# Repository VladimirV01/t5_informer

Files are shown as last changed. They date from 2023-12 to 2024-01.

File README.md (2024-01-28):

# Lilygo T5 Pro Informer for Home Assistant
This repository contains all my relevant materials, configurations and information used at building a Lilygo T5 Pro Informer for Home Assistant, based on ESP32-S3 module.
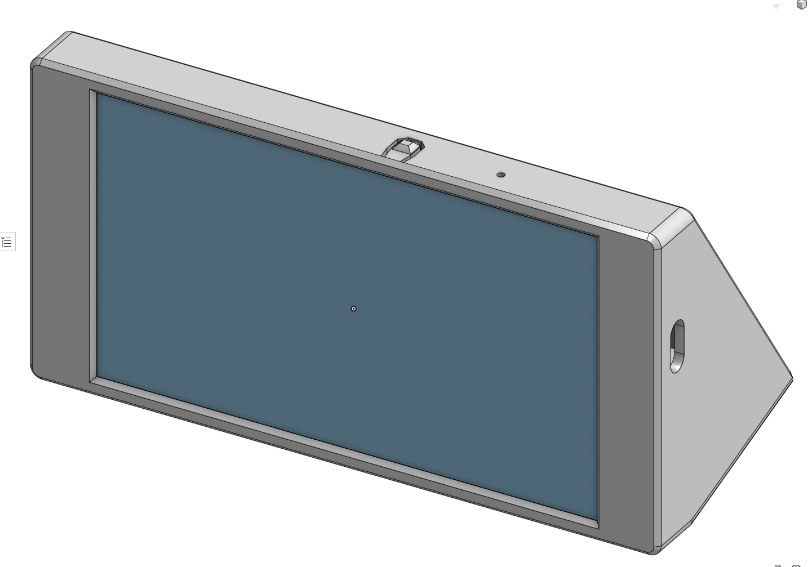
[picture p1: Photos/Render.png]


This project came to life mainly because I wanted to try the ePaper technology and check it out by myself. 
Initially I wanted to buy a bare display and make the electronics myself but I saw the Lilygo module and decided it is going to be faster to just buy it. 

At the moment of the build I had quite some trouble compiling it with ESPHome because the esp32-s3 was not fully supported at that time. As a result I had to to some digging on the internet to find a solution. 

## ESPHome Configuration File
The ESPHome yaml configuration file is `Configuration/t5_informer.yaml`. All the parameters are explained in the file.

You will notice that there are a bunch of repetitive sensors passed from HA to ESPHome for temperature forecast and event display. This is a workaround that I used to display the mentioned information since I could not manage to parse the JSON on the device itself... Any improvement here is welcome!

## ESPHome Compilation problems
As mentioned above, I had some problem compiling this project for esp32-s3 and after an extensive google search I found [this](https://github.com/esphome/feature-requests/issues/1960) feature request related to exactly Lilygo T5 Plus board.

I have folowed [this](https://github.com/esphome/feature-requests/issues/1960#issuecomment-1426388167) advice and added the file `Configuration/lilygo-t5-47-plus.json` to my device directory in `/config/esphome/.esphome/build/[my-device-name]/boards` and in the configuration file I specified the board as `lilygo-t5-47-plus` which worked like a charm and after all the manipulations I was able to flash the board and have it displaying my first letters on an ePaper display. :)

## Display Layout Configuration file
As you can observe in the ESPHome configuration file, the display layout code is in a different file and you can find it in `Configuration/t5_resources/my_display.yaml`.

In that file I have described all the bits and pieces that I consider important and hopefully it is explicit enough that anybody could easily change it to suit his/her needs.

The fonts and icons files are in the `Configuration/t5_resources/fonts/` don't forget to grab those and the `Configuration/t5_resources/common.h` file and add them to your desired directory in order to use when compiling the firmware. 

## Home Assistant part of configuration
To populate the weather and tasks related information I have added 2 template sensors on the home assistant side. 

I added them directly into the configuration.yaml file of the HA. Please check the file in `Configuration/HA_configuration.yaml`. It very clunky and I am aware there must be a more clever and better way to poll this info and if you know how to improve it, you are more than welcome. 

## 3D Print files for case
I have also designed a case for this specific board and the files to 3D print it are in the `3D_Files` directory. 

I printed it using PLA and designed the model to be printed without any support. 

[Here](https://cad.onshape.com/documents/7d4a7958a10177a50d182324/w/5a86303ea5b0b907208ba287/e/458f4cf96e62d17cedf1597b) if the link to the onshape project with the case. You can copy the project and add any changes and improvements you add because even though it is good enough for me, it is definitely far from being perfect and any improvement is welcome. 

**NOTE:** Please compile the firmware, flash it via USB and be sure the device is working and connecting to ESPHome before assembling the case. Due to some design flaws when the device is assembled the USB C connector can not reach the board. Sorry for that... :( Please modify the project and fix this issue if it annoys you too much. 

## Assembly steps
### Step 1: Get the parts
In the picture below you can see all the parts I used in the end to assemble the project. Plus add some screws and heated inserts that are not seen in the photo.
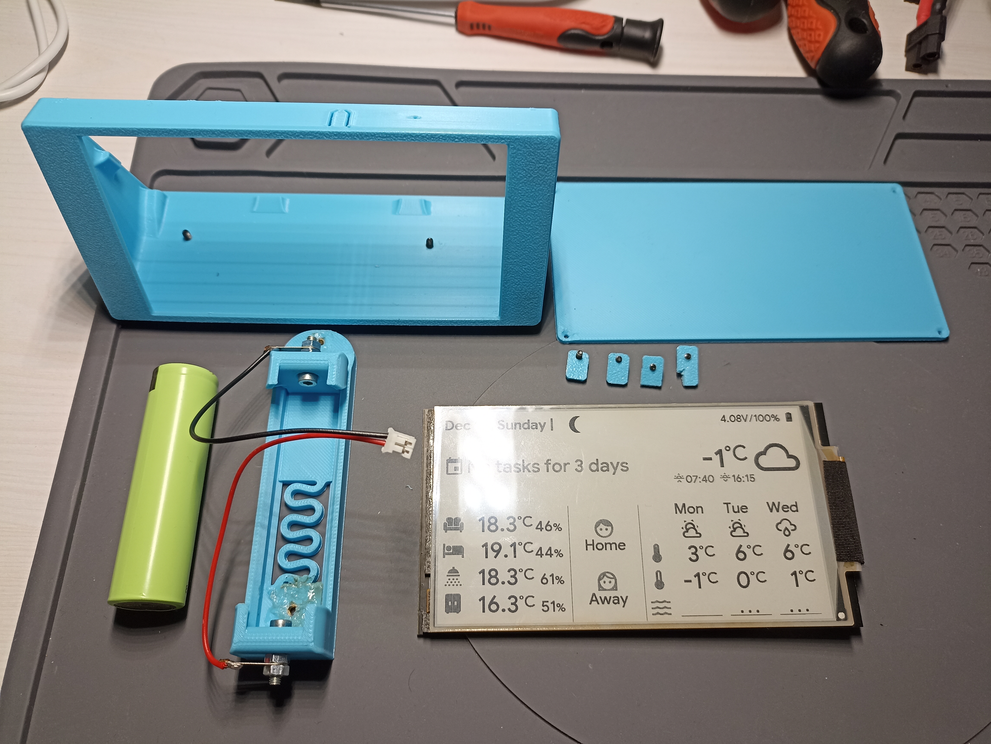
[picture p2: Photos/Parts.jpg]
Parts Parts for the project


### Step 2: Insert the bronze heated inserts into the case fixture points
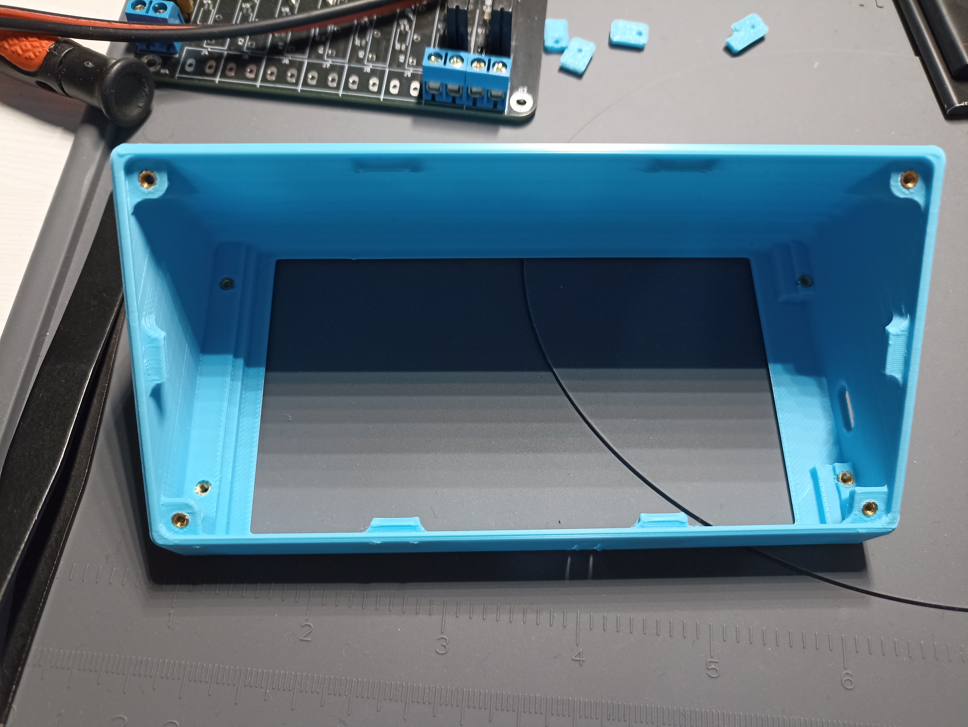
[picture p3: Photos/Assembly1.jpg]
Insert Heated Inserts Heated inserts


### Step 3: Insert the Lilygo Board
Insert the board
Please be careful at this step because you will have to fiddle the board around a bit to place it the right spot. I didn't think this step thoroughly enough and you will have to bend the upper side of the case outwards a bit so that the back lid support does not interfere with the board when inserting it.

Again: **Please be careful** not to damage your board or the ePaper display! (I have assembled an disassembled the device not less than 5 times and didn't damage mine so it is definitely doable but if you want to improve it, please adjust the 3D model using the shared link of the case project.)

### Step 4: Add the fixtures
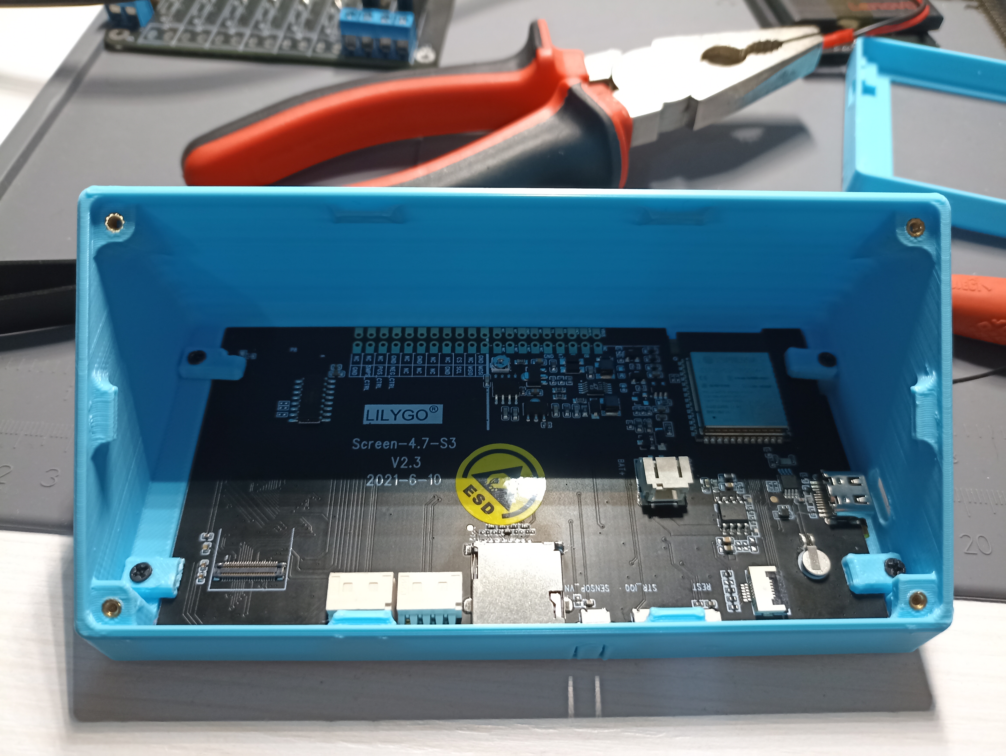
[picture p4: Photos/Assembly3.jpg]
Add the fixtures

Use some screws compatible with your heated inserts and add the printed fixtures to secure the board and the display in place.

You can see from the photos that I trimmed my fixtures after printed because those were interfering with some components on the board but on the current model this is fixed.

### Step 5: Check the functionality
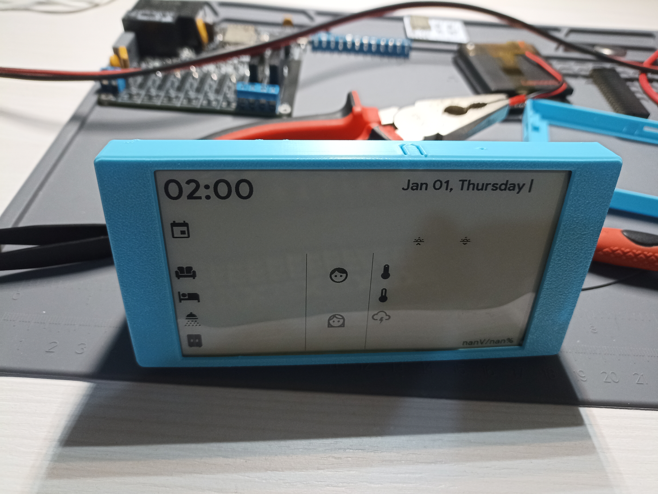
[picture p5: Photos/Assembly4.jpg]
Function check

At this point you can connect a battery and check if the device turns on and if everything is fine.

### Step 6: Add a battery
Initially I wanted to use an old phone battery that I had laying around as you can see from the photo below.
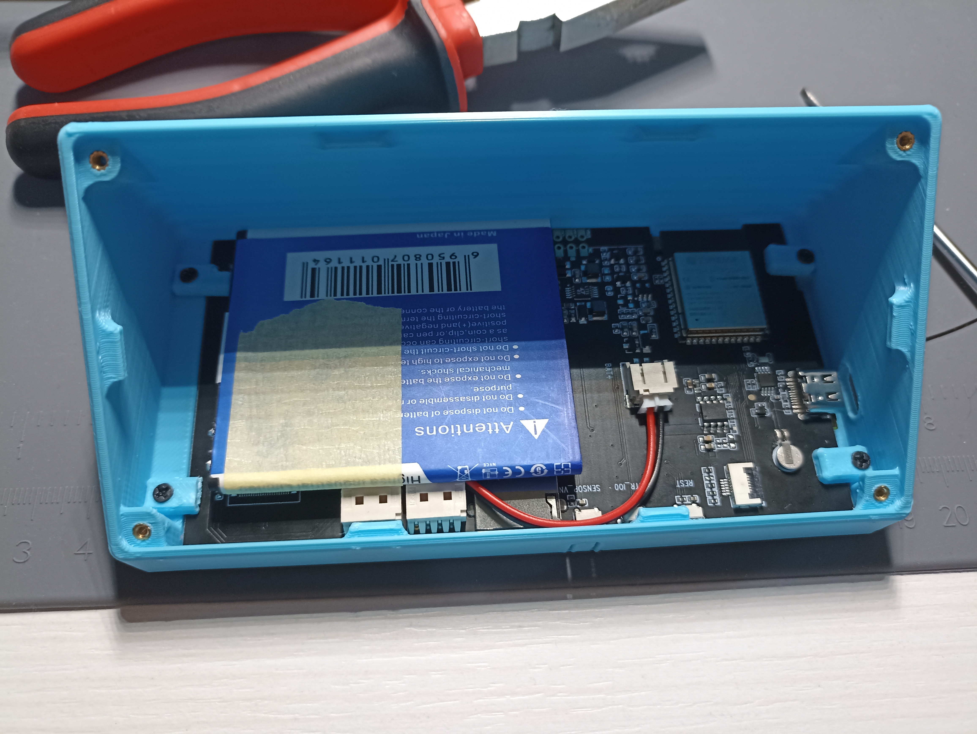
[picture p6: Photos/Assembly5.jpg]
Photo Battery Phone Battery


After some testing it turned out that the capacity degraded too much over time and the software is not yet very optimized for low enough power consumption. As a result the battery was drained very fast. So, I decided to use an 18650 cell that you can easily find anywhere. :) 

So I found [this](https://www.printables.com/model/75343-k014s-parametric-18650-battery-holder-opensource/comments/1284600) battery holder on Printables, printed it, inserted some bronze heated inserts in a very ugly way, drilled some holes in the bottom of the case and fixed it inside.

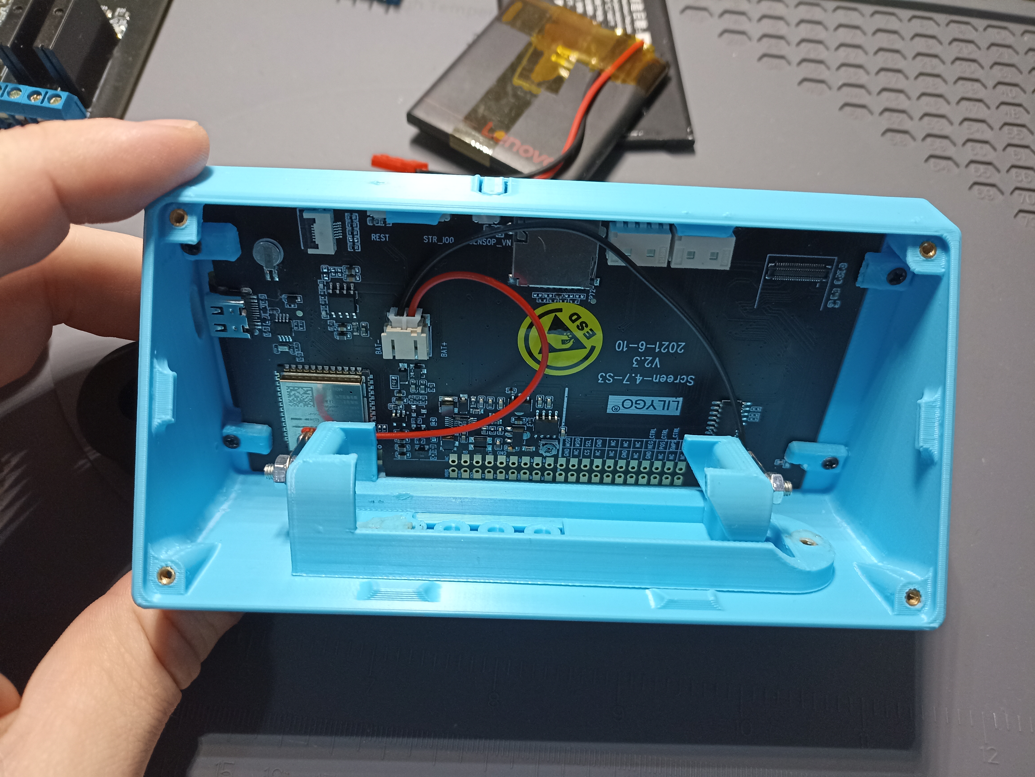
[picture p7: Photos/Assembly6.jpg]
Battery holder for 18650 inserted 18650 holder inserted


### Step 7: Charge the battery and insert it in the holder

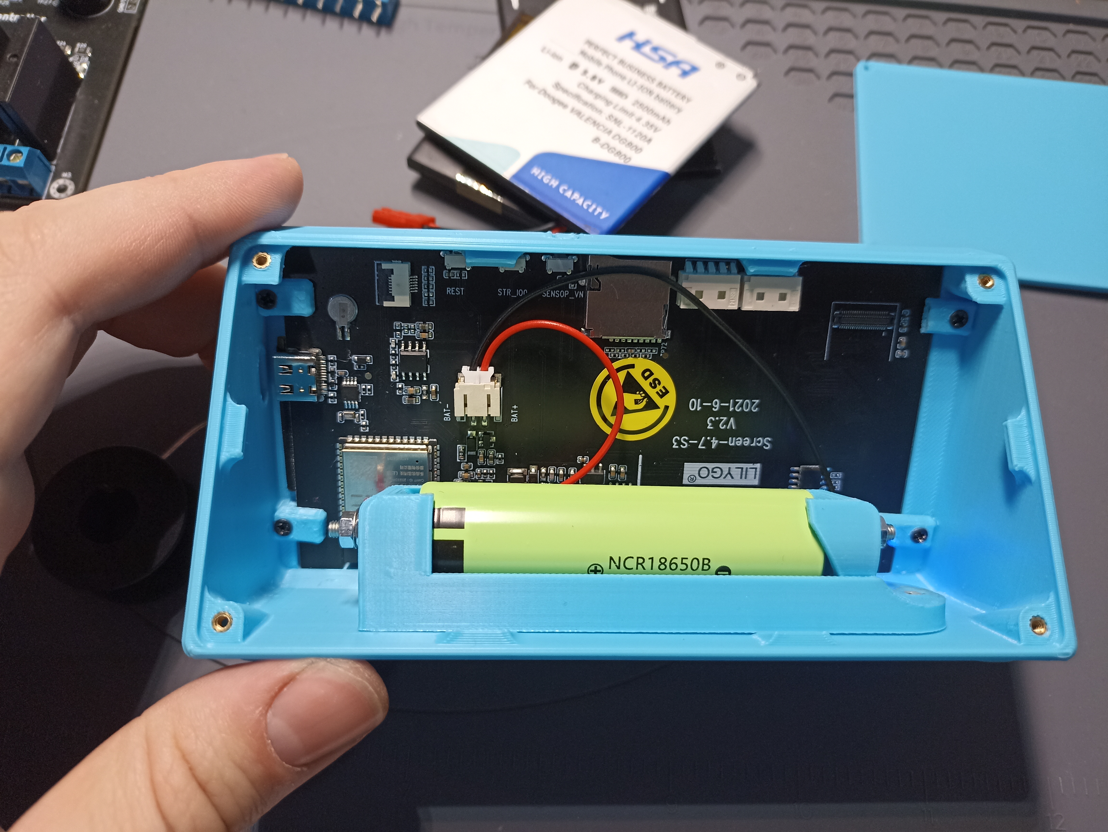
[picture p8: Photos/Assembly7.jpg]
Battery inserted Inserted battery


### Step 8: Screw the back lid in place

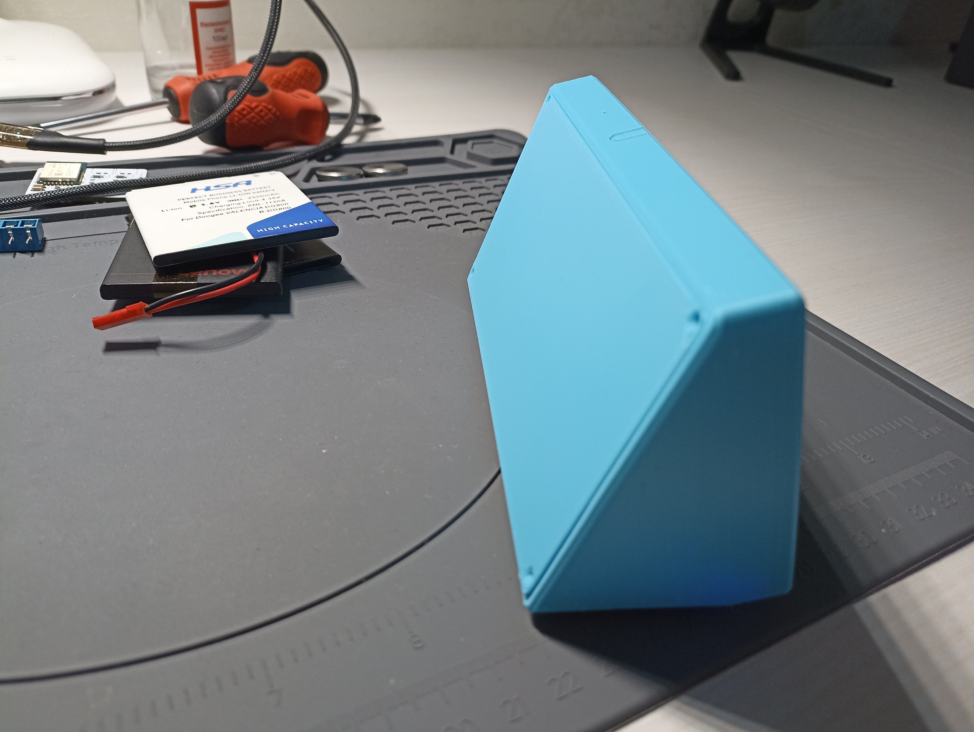
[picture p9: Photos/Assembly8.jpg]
Back lid inserted Inserted back lid


### Step 9: Enjoy!

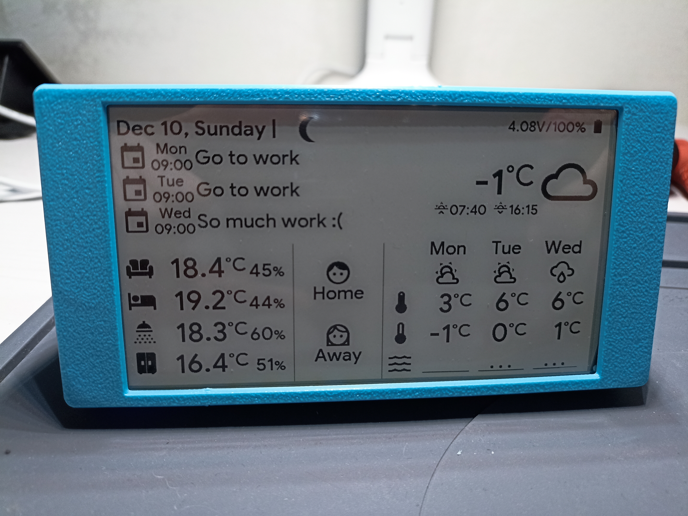
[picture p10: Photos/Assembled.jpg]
Assembled Informer


## References
Working on this project I designed the case entirely from scratch. However, the software was found in other repositories and was heavily modified by me to work for my needs.
Here are the references to the repositories and articles which I used.

[ESPHome configuration example](https://gist.github.com/Plawasan/4ae826b05aaa7812f3a191714ca47a50)

[Example of common.h file for translation functions used to convert text to icons](https://github.com/tolnai/esphome-dashboard-lilygo-t5/blob/main/common.h)

[Very useful and informative video from BeardedTinker](https://www.youtube.com/watch?v=yftae61X4i8)

[Nice display layout](https://www.reddit.com/r/homeassistant/comments/sdx5gg/yet_another_lilygo_t5_eink_esphome_dashboard/)

[Another example of ESPHome configuration](https://github.com/kotope/esphome_eink_dashboard/blob/main/eink-dashboard.yaml)

[Feature request issue which helped to compile the software](https://github.com/esphome/feature-requests/issues/1960)

## Some open issues:
1. When the battery discharges I have to take the back lid off and charge it because, as mentioned above, due to my design flaw I can not reach the connector with the USB C.
2. Make it update with a smaller frequency than hourly in the night.
3. Center the Tasks in the dedicated space when there are less than 3 tasks available.

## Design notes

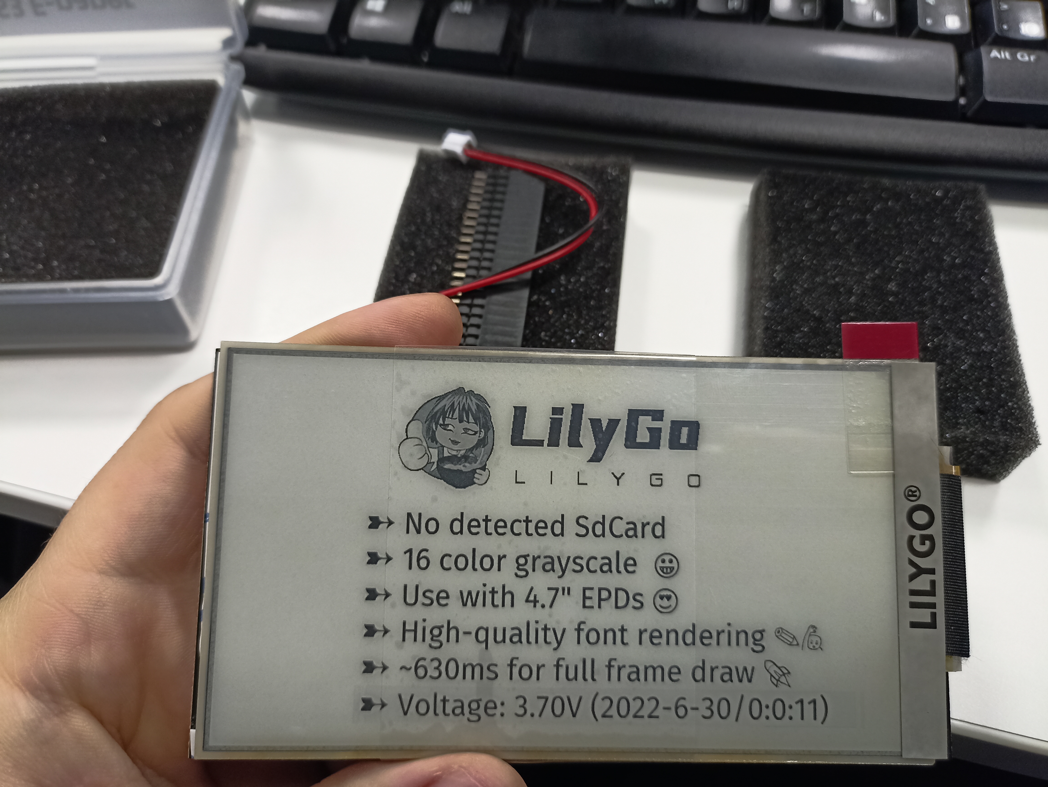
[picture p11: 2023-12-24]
Photos/EPaper.jpg

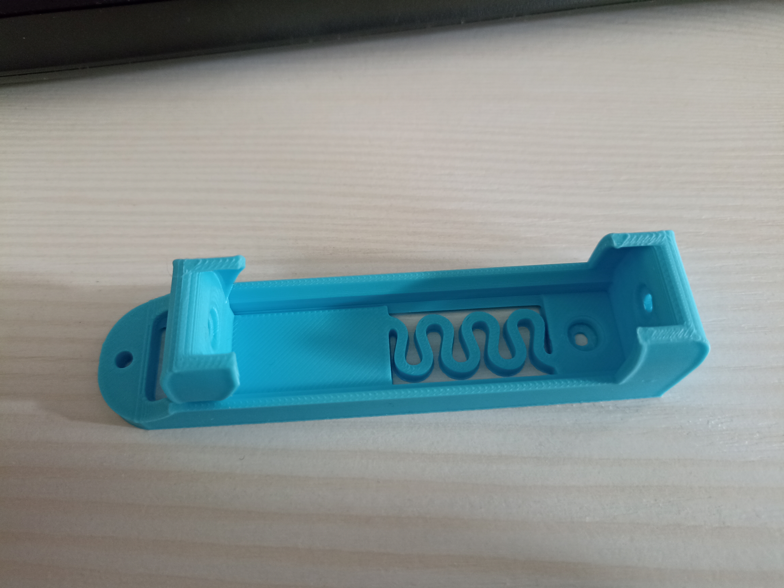
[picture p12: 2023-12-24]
Photos/Bat Holder.jpg

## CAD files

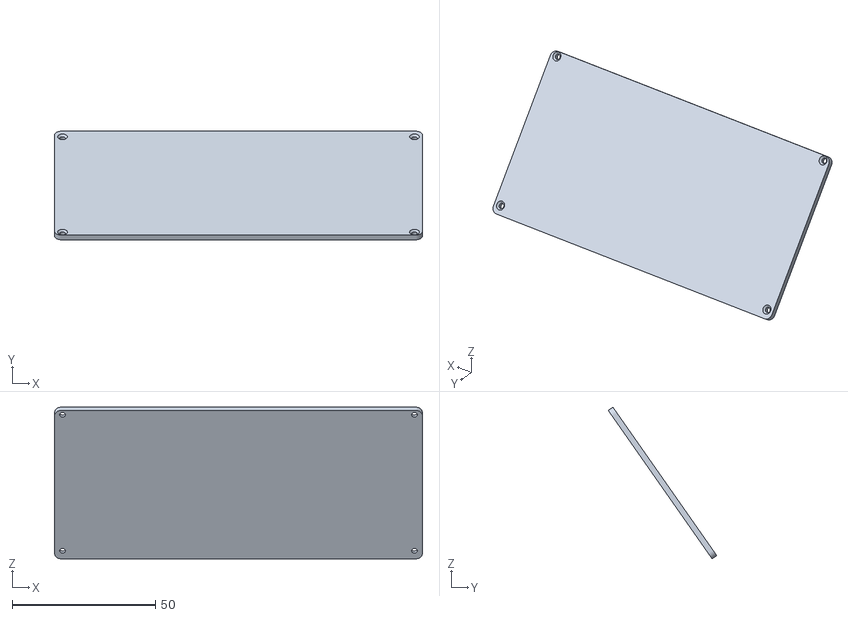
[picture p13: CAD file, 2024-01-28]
3D_Files/Lilygo Informer - Back Lid.stl
128.4 x 37.9 x 52.9

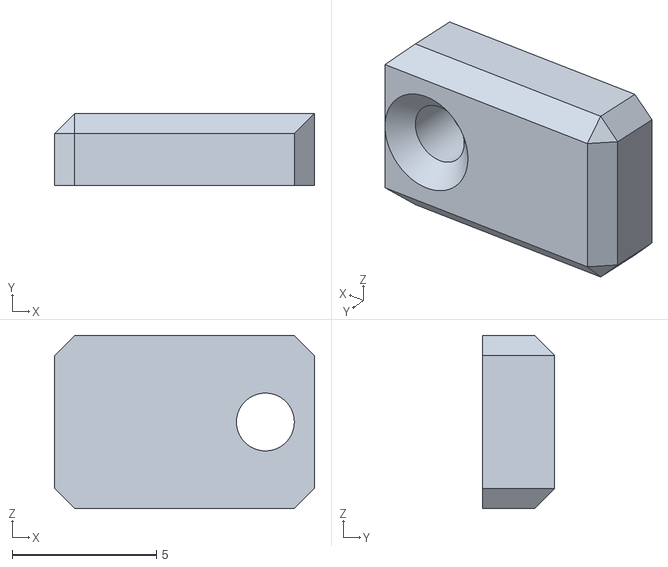
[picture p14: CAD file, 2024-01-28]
3D_Files/Lilygo Informer - Fixator Left.stl
9.00 x 2.50 x 6.00

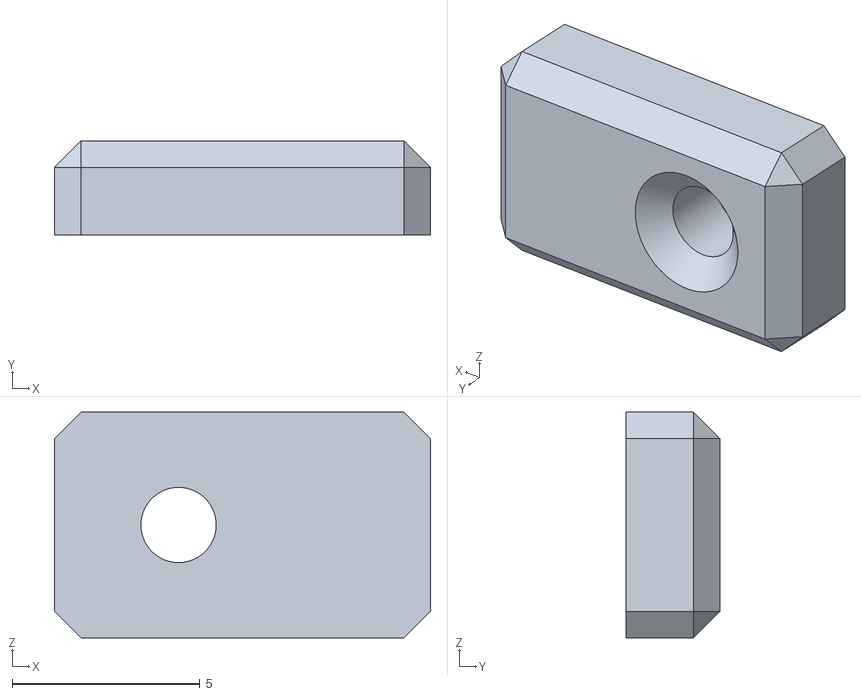
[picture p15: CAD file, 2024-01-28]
3D_Files/Lilygo Informer - Fixator Right.stl
10.0 x 2.50 x 6.00

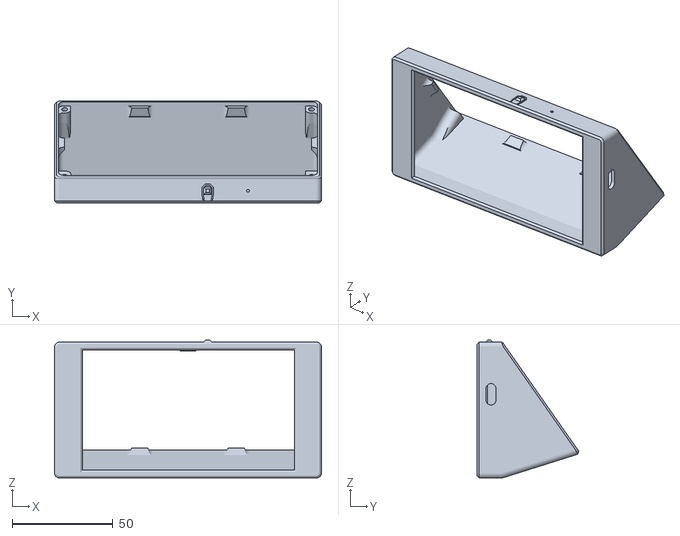
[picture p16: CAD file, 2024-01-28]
3D_Files/Lilygo Informer - Case.stl
132.8 x 50.6 x 68.6

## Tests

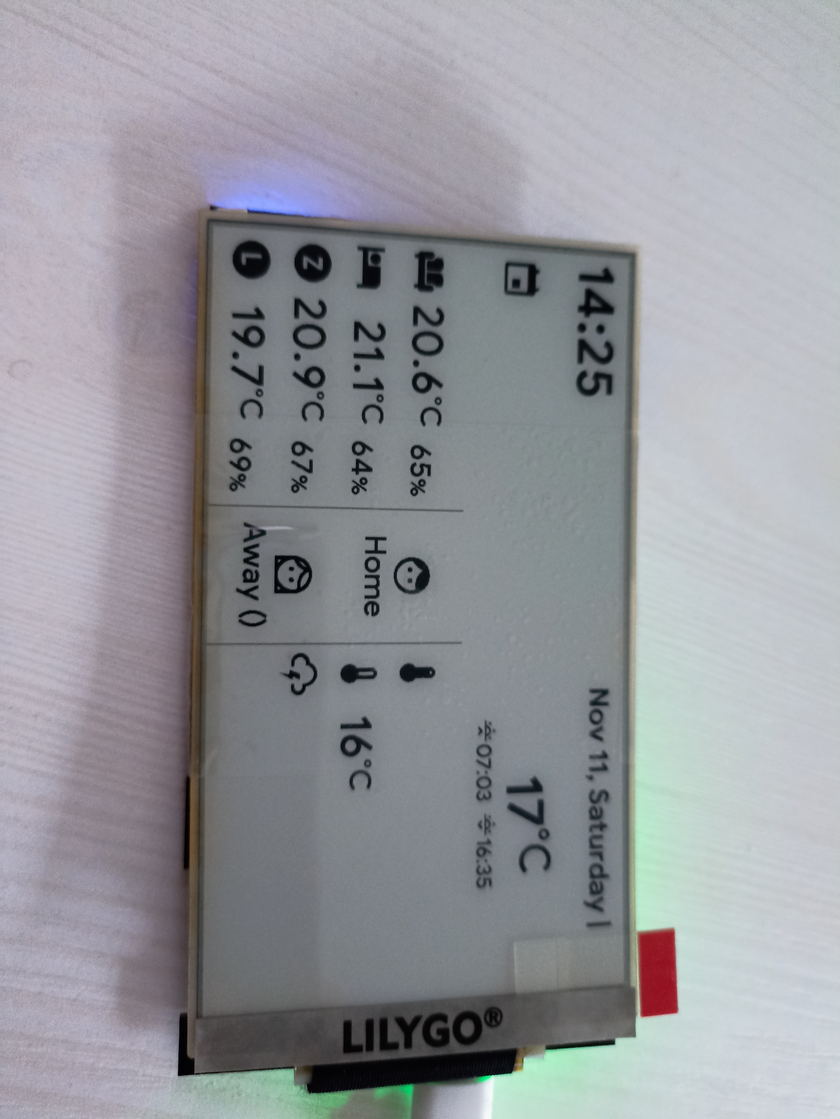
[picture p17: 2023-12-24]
Photos/First Results.jpg

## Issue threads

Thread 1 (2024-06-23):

Forecast is not working correct.

00107, 2024-06-23:
The weather forecast from Openweathermap is not working correctly. Day1 is correct, Day2 has incorrect values and Day3 provides no values. I've had this behavior for a few weeks, but I can't find a solution myself. Openweathermap itself provides correct prediction values and the API works.
Any ideas?
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

VladimirV01, 2024-06-23:
Hello @00107,

Please help me understand correctly the issue.
Was it ever working for you and suddenly stopped or you are only starting to configure it now?

Could you also share the homeasssitant configuration.yaml file part which covers the sensor that aggregates the forecast data?

00107, 2024-06-23:
Hello @VladimirV01
thanks for the quick response!
Yes, at the beginning it worked perfectly for several weeks. Suddenly the forecast values   for the third day were missing. Upon closer inspection I noticed that even for day 2 the values   did not match those shown by Openweathermap for this location. Day1 values are ok.
That's strange, isn't it?

This is my yaml of the sensor: https://wastebin.diefe.de/-3xY5a.yaml

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

VladimirV01, 2024-06-23:
@00107,

I have checked the sensor and it looks exactly as mine, which is still working as expected.

Could you please run the service "weather.get_forecasts" from home assistant and share the output?
I presume the issue is somewhere around here.

00107, 2024-06-23:
I first had to look at how to run a service... ;-) I hope I did it right. Here is the output:
`weather.openweathermap:
  forecast:
    - datetime: "2024-06-23T09:00:00+00:00"
      condition: partlycloudy
      temperature: 20.1
      pressure: 1019
      cloud_coverage: 19
      wind_speed: 4.43
      wind_bearing: 328
      uv_index: 5.14
      precipitation_probability: 0
      precipitation: 0
      apparent_temperature: 20
      dew_point: 14.7
      wind_gust_speed: 5.26
      humidity: 71
    - datetime: "2024-06-23T10:00:00+00:00"
      condition: partlycloudy
      temperature: 20.4
      pressure: 1019
      cloud_coverage: 21
      wind_speed: 3.74
      wind_bearing: 12
      uv_index: 4.52
      precipitation_probability: 0
      precipitation: 0
      apparent_temperature: 20.3
      dew_point: 14.8
      wind_gust_speed: 6.7
      humidity: 70
    - datetime: "2024-06-23T11:00:00+00:00"
      condition: partlycloudy
      temperature: 20.6
      pressure: 1019
      cloud_coverage: 22
      wind_speed: 4.5
      wind_bearing: 54
      uv_index: 2.96
      precipitation_probability: 0
      precipitation: 0
      apparent_temperature: 20.5
      dew_point: 14.7
      wind_gust_speed: 6.91
      humidity: 69
    - datetime: "2024-06-23T12:00:00+00:00"
      condition: partlycloudy
      temperature: 20.9
      pressure: 1019
      cloud_coverage: 25
      wind_speed: 6.05
      wind_bearing: 48
      uv_index: 4.66
      precipitation_probability: 0
      precipitation: 0
      apparent_temperature: 20.8
      dew_point: 14.8
      wind_gust_speed: 7.45
      humidity: 68
    - datetime: "2024-06-23T13:00:00+00:00"
      condition: cloudy
      temperature: 21.3
      pressure: 1018
      cloud_coverage: 64
      wind_speed: 6.48
      wind_bearing: 31
      uv_index: 6.12
      precipitation_probability: 0
      precipitation: 0
      apparent_temperature: 21.2
      dew_point: 14.7
      wind_gust_speed: 7.45
      humidity: 66
    - datetime: "2024-06-23T14:00:00+00:00"
      condition: cloudy
      temperature: 22.2
      pressure: 1017
      cloud_coverage: 67
      wind_speed: 7.45
      wind_bearing: 32
      uv_index: 3.17
      precipitation_probability: 0
      precipitation: 0
      apparent_temperature: 22.1
      dew_point: 15
      wind_gust_speed: 10.01
      humidity: 64
    - datetime: "2024-06-23T15:00:00+00:00"
      condition: cloudy
      temperature: 22.8
      pressure: 1017
      cloud_coverage: 76
      wind_speed: 9.07
      wind_bearing: 36
      uv_index: 2.61
      precipitation_probability: 0
      precipitation: 0
      apparent_temperature: 22.8
      dew_point: 15.5
      wind_gust_speed: 11.74
      humidity: 64
    - datetime: "2024-06-23T16:00:00+00:00"
      condition: rainy
      temperature: 22.4
      pressure: 1017
      cloud_coverage: 70
      wind_speed: 12.46
      wind_bearing: 31
      uv_index: 1.15
      precipitation_probability: 20
      precipitation: 0.16
      apparent_temperature: 22.5
      dew_point: 16.3
      wind_gust_speed: 13.82
      humidity: 69
    - datetime: "2024-06-23T17:00:00+00:00"
      condition: rainy
      temperature: 21.5
      pressure: 1017
      cloud_coverage: 73
      wind_speed: 11.12
      wind_bearing: 27
      uv_index: 0.64
      precipitation_probability: 23
      precipitation: 0.1
      apparent_temperature: 21.8
      dew_point: 17.1
      wind_gust_speed: 17.14
      humidity: 77
    - datetime: "2024-06-23T18:00:00+00:00"
      condition: cloudy
      temperature: 20.6
      pressure: 1017
      cloud_coverage: 78
      wind_speed: 7.02
      wind_bearing: 26
      uv_index: 0.26
      precipitation_probability: 3
      precipitation: 0
      apparent_temperature: 20.9
      dew_point: 17.5
      wind_gust_speed: 13.79
      humidity: 83
    - datetime: "2024-06-23T19:00:00+00:00"
      condition: rainy
      temperature: 18.9
      pressure: 1018
      cloud_coverage: 55
      wind_speed: 8.42
      wind_bearing: 31
      uv_index: 0
      precipitation_probability: 87
      precipitation: 0.24
      apparent_temperature: 19
      dew_point: 15.7
      wind_gust_speed: 7.13
      humidity: 83
    - datetime: "2024-06-23T20:00:00+00:00"
      condition: rainy
      temperature: 17.3
      pressure: 1019
      cloud_coverage: 52
      wind_speed: 9.61
      wind_bearing: 35
      uv_index: 0
      precipitation_probability: 82
      precipitation: 0.14
      apparent_temperature: 17.4
      dew_point: 15.1
      wind_gust_speed: 13.82
      humidity: 88
    - datetime: "2024-06-23T21:00:00+00:00"
      condition: cloudy
      temperature: 16.4
      pressure: 1019
      cloud_coverage: 57
      wind_speed: 8.93
      wind_bearing: 32
      uv_index: 0
      precipitation_probability: 54
      precipitation: 0
      apparent_temperature: 16.5
      dew_point: 14.8
      wind_gust_speed: 12.6
      humidity: 90
    - datetime: "2024-06-23T22:00:00+00:00"
      condition: partlycloudy
      temperature: 15.7
      pressure: 1019
      cloud_coverage: 48
      wind_speed: 8.5
      wind_bearing: 38
      uv_index: 0
      precipitation_probability: 32
      precipitation: 0
      apparent_temperature: 15.7
      dew_point: 14.3
      wind_gust_speed: 8.68
      humidity: 92
    - datetime: "2024-06-23T23:00:00+00:00"
      condition: partlycloudy
      temperature: 15.3
      pressure: 1019
      cloud_coverage: 42
      wind_speed: 8.35
      wind_bearing: 41
      uv_index: 0
      precipitation_probability: 15
      precipitation: 0
      apparent_temperature: 15.3
      dew_point: 14
      wind_gust_speed: 9.97
      humidity: 93
    - datetime: "2024-06-24T00:00:00+00:00"
      condition: partlycloudy
      temperature: 14.8
      pressure: 1019
      cloud_coverage: 37
      wind_speed: 8.96
      wind_bearing: 40
      uv_index: 0
      precipitation_probability: 3
      precipitation: 0
      apparent_temperature: 14.8
      dew_point: 13.8
      wind_gust_speed: 14.04
      humidity: 94
    - datetime: "2024-06-24T01:00:00+00:00"
      condition: sunny
      temperature: 14.5
      pressure: 1019
      cloud_coverage: 0
      wind_speed: 9
      wind_bearing: 40
      uv_index: 0
      precipitation_probability: 0
      precipitation: 0
      apparent_temperature: 14.4
      dew_point: 13.4
      wind_gust_speed: 17.1
      humidity: 94
    - datetime: "2024-06-24T02:00:00+00:00"
      condition: sunny
      temperature: 14.2
      pressure: 1019
      cloud_coverage: 2
      wind_speed: 8.75
      wind_bearing: 46
      uv_index: 0
      precipitation_probability: 0
      precipitation: 0
      apparent_temperature: 14.1
      dew_point: 13.1
      wind_gust_speed: 16.85
      humidity: 95
    - datetime: "2024-06-24T03:00:00+00:00"
      condition: sunny
      temperature: 13.8
      pressure: 1019
      cloud_coverage: 4
      wind_speed: 8.78
      wind_bearing: 45
      uv_index: 0
      precipitation_probability: 0
      precipitation: 0
      apparent_temperature: 13.8
      dew_point: 12.9
      wind_gust_speed: 16.45
      humidity: 95
    - datetime: "2024-06-24T04:00:00+00:00"
      condition: sunny
      temperature: 13.8
      pressure: 1019
      cloud_coverage: 4
      wind_speed: 9.07
      wind_bearing: 44
      uv_index: 0.1
      precipitation_probability: 0
      precipitation: 0
      apparent_temperature: 13.7
      dew_point: 12.9
      wind_gust_speed: 18.86
      humidity: 95
    - datetime: "2024-06-24T05:00:00+00:00"
      condition: sunny
      temperature: 15.1
      pressure: 1019
      cloud_coverage: 4
      wind_speed: 9
      wind_bearing: 47
      uv_index: 0.42
      precipitation_probability: 0
      precipitation: 0
      apparent_temperature: 15.1
      dew_point: 14
      wind_gust_speed: 25.81
      humidity: 94
    - datetime: "2024-06-24T06:00:00+00:00"
      condition: sunny
      temperature: 17
      pressure: 1019
      cloud_coverage: 3
      wind_speed: 13.21
      wind_bearing: 57
      uv_index: 1.15
      precipitation_probability: 0
      precipitation: 0
      apparent_temperature: 17.1
      dew_point: 15
      wind_gust_speed: 25.34
      humidity: 89
    - datetime: "2024-06-24T07:00:00+00:00"
      condition: sunny
      temperature: 18.7
      pressure: 1019
      cloud_coverage: 0
      wind_speed: 14.44
      wind_bearing: 64
      uv_index: 2.4
      precipitation_probability: 0
      precipitation: 0
      apparent_temperature: 18.8
      dew_point: 15.7
      wind_gust_speed: 22.64
      humidity: 83
    - datetime: "2024-06-24T08:00:00+00:00"
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
00107, 2024-06-23:
I have the feeling that it is due to the query type. If I select "hourly" when running the service, the values   end after two days. If I select "daily" I get forecast data for the next 7 days.

For testing purposes I set the configuration.yaml to Daily. Now I get values   for day 3, but the min/max calculation and condition is no longer correct. --> https://wastebin.diefe.de/YoqZ5c.yaml

 I use API V3.0, could it be related to that?

VladimirV01, 2024-06-23:
Yes, you are correct. Your hourly forecast contains data for current and two more days, however the informer show the data for the next 3 days.

On the other hand, you could use the daily forecast built into openwethermap sin e it is available for you, and there is no need to make all the calculations, as I did.

If you want to share a sample of daily forecast returned by the service, I can check later today how the sensor could be modified to use your data.

00107, 2024-06-23:
> If you want to share a sample of daily forecast returned by the service, I can check later today how the sensor could be modified to use your data.

That would be great, thank you! :)
Sample data of daily forecast: https://wastebin.diefe.de/3n0IPc.yaml

00107, 2024-06-23:
@VladimirV01
I have tried to adapt the code myself in the meantime. It works so far, but I am not sure if everything is correct. Unfortunately, my coding knowledge is not that good...
https://wastebin.diefe.de/0b+5mb.yaml

VladimirV01, 2024-06-23:
@00107,

Your template looks good!

Unfortunately I can not test it on my setup since the daily forecast is not available for the free version, but it should be working fine.
Does it display the correct information on your device?

00107, 2024-06-23:
Yes, the display looks good so far.
Thanks again for your great work and support. I think this issue can be closed.

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

00107, 2024-06-23:
Yes, the display looks good so far.
Thanks again for your great work and support. I think this issue can be closed.

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

Closed 2024-06-23.

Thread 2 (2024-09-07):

Error in the code

balbulator, 2024-09-07:
Hello, I want to thank you for the good work. Checking the operation of the weather forecast sensors in HA, I saw errors in the code, namely extra brackets in the forecast attributes
You do:
`day2_condition: "{{ (full_data['weather.openweathermap']['forecast'] | selectattr('datetime', 'search', (now().date() + timedelta(days=2)) | string ) | join(', ', attribute='condition') }}"`
and it should be like this:
`"{{ full_data['weather.openweathermap']['forecast'] | selectattr('datetime', 'search', (now().date() + timedelta(days=2)) | string ) | join(', ', attribute='condition') }}"`
this is seen in multiple attributes (the first parenthesis is redundant)
Sorry for my English

VladimirV01, 2024-09-07:
Hello @balbulator,

Thank you for pointing it out to me.
I do agree there are errors and the general configuration example was awful. :)

Anyway, I took this opportunity and used some AI magic to rewrite the HA configuration example and make it more readable, optimized and efficient.
Please take a look and if you find something else which is wrong, don't hesitate to point it out to me in a new issue!

VladimirV01, 2024-09-07:
Actually, I was too naïve to believe that the AI "improved" code was actually going to work, so after testing it turned out to be broken.
As a result I reverted to the initial config, just removed the suggested parentheses.

Closed 2024-09-07.

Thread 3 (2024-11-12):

Screw size?

chinswain, 2024-11-12:
I've just printed your case and need to order some of the heated insert and screws, could I ask what sizes you used?

VladimirV01, 2024-11-13:
Hello @chinswain,
I have used M2x5 screws and the inserts are M2x5x5.

chinswain, 2024-11-13:
Thanks - ordered and printing the case now!

Closed 2024-11-13.

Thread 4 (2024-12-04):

Operating time on battery ?

minigranis, 2024-12-04:
Hello.
Intresting projekt, can you tell me how long the battery lasts in your application ?

Brg

VladimirV01, 2024-12-04:
Hello.

This is complex question. In my application with the code posted on the repository it was working around 5-6 days for me when the battery was healthy. And this was way below my expectations. It demotivated me to work on improving the project.

Since then, I have discharged the battery under the lower allowed threshold and its capacity has degraded. Now it works around 3 days on a charge.

Over discharging the battery is really a concern in this application because the board has no protection integrated for this scenario. You should either send some alarms to your phone from HASS when the battery is low, and charge it before its voltage is below allowed values or add a cheap battery protection PCB, which will protect the battery.

Also, there are several improvements which can be made to the code and this should have significant impact on battery life.
1. Improve the code to update only once after wake up, when all the needed data is collected and ready to be presented. _Currently it updates 3 or 4 times when it wakes up._
2. Make the sleep time adaptive and don't wake up ad night.
3. Keep track if there is somebody at home or not. If nobody is at home, immediately go back to sleep without updating the screen.

When I have some spare time and motivation, maybe I will work on implementing the mentioned improvements.

Cheers!

minigranis, 2024-12-05:
Thanks, I know its a complex matter but your answer has given me an idea as what to expect.

Closed 2024-12-05.

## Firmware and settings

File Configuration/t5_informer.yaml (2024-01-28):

---
substitutions:
  device: t5_informer
  name: "Lilygo Informer"
  ip_address: 192.168.100.75
  ip_gw: 192.168.100.1
  ip_netmask: 255.255.255.0
  run_time: 2min
  sleep_time: 1h
  night_sleep_time: 6h # This is not used yet

esphome:
  name: ${device}
  friendly_name: ${name}
  includes:
    - t5_resources/common.h
  on_boot:
    then:
      - pcf8563.read_time:  # Update the RTC
      - script.execute: sleep_routine  # Running the script to prevent the device from entering deep sleep if there is an update pending.

  platformio_options:
    board_dir: boards
    board: lilygo-t5-47-plus

esp32:
  variant: esp32s3
  board: lilygo-t5-47-plus
  framework:
    type: arduino

logger:

api:
  encryption:
    key: <EDITED>

ota:

wifi:
  networks:
    - ssid: !secret iot_network_ssid
      password: !secret iot_network_password
  manual_ip:
    static_ip: ${ip_address}
    gateway: ${ip_gw}
    subnet: ${ip_netmask}

  ap:
    ssid: "AP ${name}"
    password: !secret wifi_ap_password

captive_portal:

web_server:
  port: 80
  include_internal: True

sun:
  latitude: 47.032292°
  longitude: 28.766057°

binary_sensor:
  - platform: homeassistant # This imports the input boolean from the homeassistant to check if there is pending update
    id: update
    internal: true
    entity_id: input_boolean.esphome_pending_update
# The physical button is commented because it is used for wake up from deep sleep. 
# If you want to use it for other purposes, comment the deep sleep section   
#  - platform: gpio
#    pin: 
#      number: GPIO21 #was GPIO39 on the previous board
#      inverted: true
#    name: "Button 1"
#    on_press:
#      - logger.log: Physical Button Pressed



i2c:
  sda: GPIO18
  scl: GPIO17
  scan: false
  id: rtc_bus
  frequency: 100khz

time:
  - platform: pcf8563
    id: pcf_time
    address: 0x51  
    update_interval: never
  - platform: homeassistant
    id: ntp
    timezone: Europe/Chisinau
    on_time_sync:
      then:
        - pcf8563.write_time:
        - component.update: sunrise
        - component.update: sunset

external_components:
  - source: github://nickolay/esphome-lilygo-t547plus
    components: ["t547"]
  - source: github://kaeltis/esphome-lilygo-t547plus
    components: ["lilygo_t5_47_battery"]

sensor:
  - platform: lilygo_t5_47_battery
    id: battery_voltage
    voltage:
      name: "Battery Voltage"

  - platform: template
    name: "Battery Percentage"
    id: battery_percentage
    lambda: |-
      // tweak values in mapping for calibration
      // 4.1 = max voltage
      // 3.3 = min voltage
      float y = (id(battery_voltage).voltage->state - 3.3) * 100.0 / (4.1 - 3.3);
      if (y < 100.0) 
      { return y; } 
      else if (y < 0)
      { return 0.0; }
      else { return 100.0; };
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

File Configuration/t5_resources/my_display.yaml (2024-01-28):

---
font:
  - file: "t5_resources/Google_Sans_Medium.ttf"
    id: font_small
    size: 28    
    glyphs: |-
      !"%()+=,-_.:°0123456789ABCDEFGHIJKLMNOPQRSTUVWXYZ abcdefghijklmnopqrstuvwxyz'/&|ÁÉÍÓÖŐÚÜŰáéíóöőúüű
  - file: "t5_resources/Google_Sans_Medium.ttf"
    id: font_medium
    size: 38
    glyphs: |-
      !"%()+=,-_.:°0123456789ABCDEFGHIJKLMNOPQRSTUVWXYZ abcdefghijklmnopqrstuvwxyz'/&|ÁÉÍÓÖŐÚÜŰáéíóöőúüű
  - file: "t5_resources/Google_Sans_Bold.ttf"
    id: font_medium_bold
    size: 38
    glyphs: |-
      !"%()+=,-_.:°0123456789ABCDEFGHIJKLMNOPQRSTUVWXYZ abcdefghijklmnopqrstuvwxyz'/&|ÁÉÍÓÖŐÚÜŰáéíóöőúüű
  - file: "t5_resources/Google_Sans_Medium.ttf"
    id: font_big
    size: 48
    glyphs: |-
      !"%()+=,-_.:°0123456789ABCDEFGHIJKLMNOPQRSTUVWXYZ abcdefghijklmnopqrstuvwxyz'/&|ÁÉÍÓÖŐÚÜŰáéíóöőúüű
  - file: "t5_resources/Google_Sans_Medium.ttf"
    id: font_large
    size: 56
    glyphs: |-
      !"%()+=,-_.:°0123456789ABCDEFGHIJKLMNOPQRSTUVWXYZ abcdefghijklmnopqrstuvwxyz'/&|ÁÉÍÓÖŐÚÜŰáéíóöőúüű
  - file: "t5_resources/Google_Sans_Bold.ttf"
    id: font_xlarge_bold
    size: 72
    glyphs: |-
      !"%()+=,-_.:°0123456789ABCDEFGHIJKLMNOPQRSTUVWXYZ abcdefghijklmnopqrstuvwxyz'/&|ÁÉÍÓÖŐÚÜŰáéíóöőúüű
  # material UI icons - from https://pictogrammers.github.io/@mdi/font/5.3.45/
  - file: 't5_resources/materialdesignicons-webfont.ttf'
    id: font_icons
    size: 130
    glyphs:
      - "\U000F0594" # clear-night
      - "\U000F0590" # cloudy
      - "\U000F0591" # fog
      - "\U000F0592" # hail
      - "\U000F0593" # lightning
      - "\U000F067E" # lightning-rainy
      - "\U000F0F31" # night-partly-cloudy
      - "\U000F0595" # partly-cloudy
      - "\U000F0596" # pouring
      - "\U000F0597" # rainy
      - "\U000F0F36" # snowy
      - "\U000F067F" # snowy-rainy
      - "\U000F0599" # sunny
      - "\U000F059D" # windy
      - "\U000F059E" # windy-variant
      - "\U000F0F38" # exCentereptional
  - file: 't5_resources/materialdesignicons-webfont.ttf'
    id: font_icons_small
    size: 56
    glyphs:
      # weather
      - "\U000F0594" # clear-night
      - "\U000F0590" # cloudy
      - "\U000F0591" # fog
      - "\U000F0592" # hail
      - "\U000F0593" # lightning
      - "\U000F067E" # lightning-rainy
      - "\U000F0F31" # night-partly-cloudy
      - "\U000F0595" # partly-cloudy
      - "\U000F0596" # pouring
      - "\U000F0597" # rainy
      - "\U000F0F36" # snowy
      - "\U000F067F" # snowy-rainy
      - "\U000F0599" # sunny
      - "\U000F059D" # windy
      - "\U000F059E" # windy-variant
      - "\U000F0F38" # exceptional
      # moon phases
      - "\U000F0F61" # moon-first-quarter
      - "\U000F0F62" # moon-full
      - "\U000F0F63" # moon-last-quarter
      - "\U000F0F64" # moon-new
      - "\U000F0F65" # moon-waning-crescent
      - "\U000F0F66" # moon-waning-gibbous
      - "\U000F0F67" # moon-waxing-crescent
      - "\U000F0F68" # moon-waxing-gibbous
      # other icons
      - "\U000F10C2" # Temperature High
      - "\U000F10C3" # Temperature Low
      - "\U000F054B" # umbrella
      - "\U000F02E3" # Bed
      - "\U000F064D" # human-male
      - "\U000F0649" # human-female
      - "\U000F0C0D" # L circle
      - "\U000F0C37" # Z circle      
      - "\U000F0F90" # Wardrobe
      - "\U000F09A1" # Shower Head   
      - "\U000F04B9" # sofa
      - "\U000F04DB" # stop
      - "\U000F040A" # play
      - "\U000F03E4" # pause
      - "\U000F0643" # man
      - "\U000F1078" # woman
      - "\U000F00ED" # calendar
      - "\U000F078D" # water level
      # Battery Icons
      - "\U000F007A" # Battery 0
      - "\U000F007C" # Battery 30
      - "\U000F007E" # Battery 50
      - "\U000F0081" # Battery 80
      - "\U000F0079" # Battery 100

  - file: 't5_resources/materialdesignicons-webfont.ttf'
    id: font_icons_tiny
    size: 32
    glyphs:
      - "\U000F005E" # arrow-up-thick
      - "\U000F0046" # arrow-down-thick
      - "\U000F059C" # Sunrise
      - "\U000F059B" # Sunset
      # Battery Icons
      - "\U000F007A" # Battery 0
      - "\U000F007C" # Battery 30
      - "\U000F007E" # Battery 50
      - "\U000F0081" # Battery 80
      - "\U000F0079" # Battery 100
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
